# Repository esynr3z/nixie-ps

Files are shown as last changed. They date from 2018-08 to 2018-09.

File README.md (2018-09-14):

# Nixie power supply

## Features

High voltage flyback converter for nixie tubes

* Input voltage: 5V - 12V
* Output voltage: 150V - 200V
* Output power: 180V 20mA @ 5V in, 180V 40mA @ 12V in

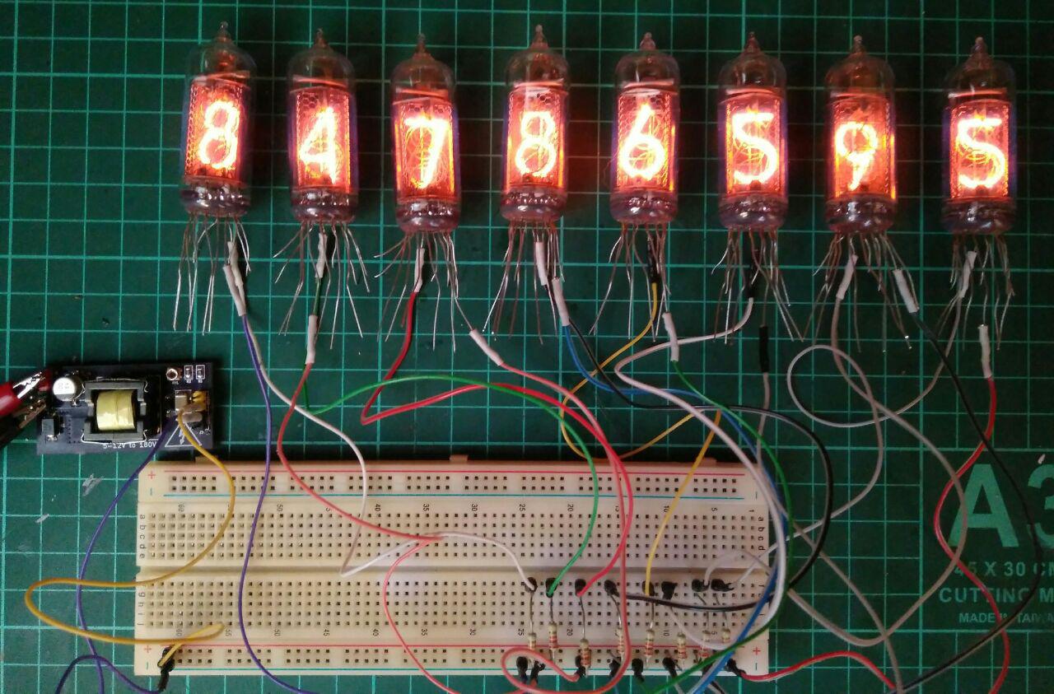
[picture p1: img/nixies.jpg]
nixies


## Board

Schematic and pcb layout created in KiCad 6 Nightly Build (compatible with KiCad 5). Converter also have been simulated with LTspice XVII.

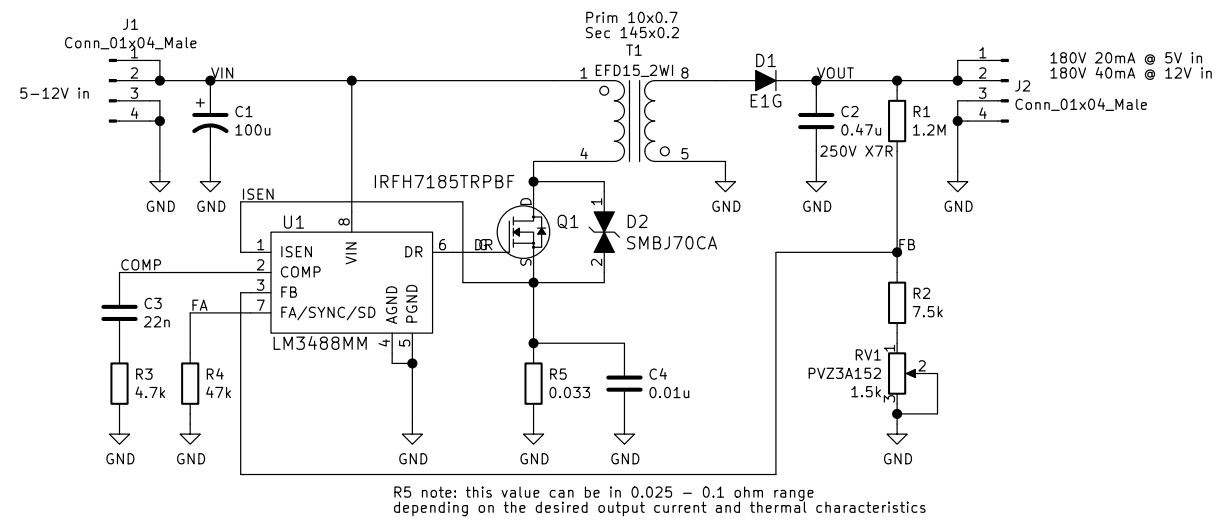
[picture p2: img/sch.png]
schematic

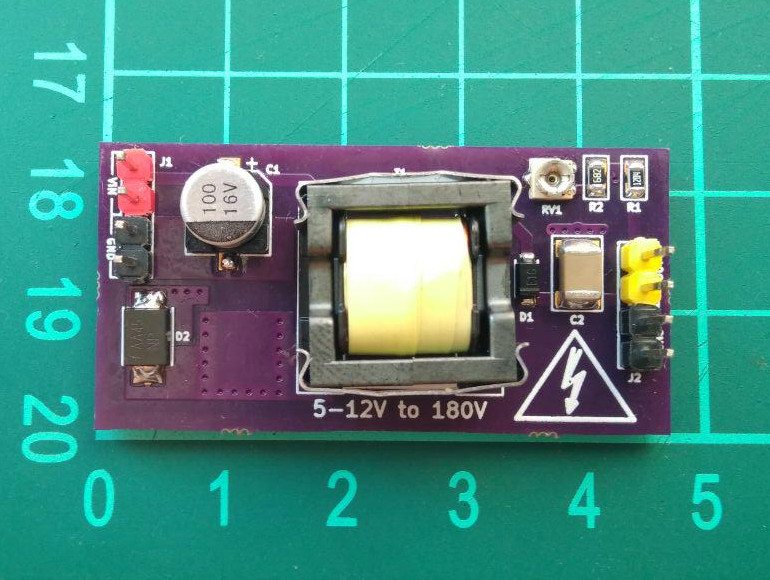
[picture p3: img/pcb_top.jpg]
pcb top

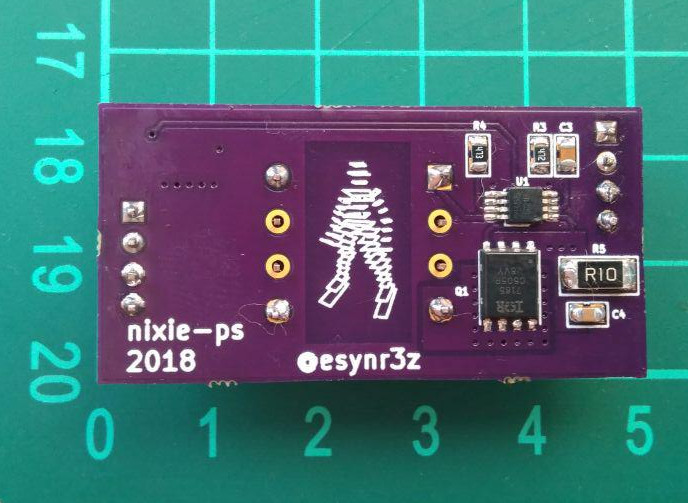
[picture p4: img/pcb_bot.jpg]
pcb bottom


[Order board v1.0 from OSH Park](https://oshpark.com/shared_projects/xFiD4IsX)

## Testing

### 5V input

Drain and gate oscillograms:
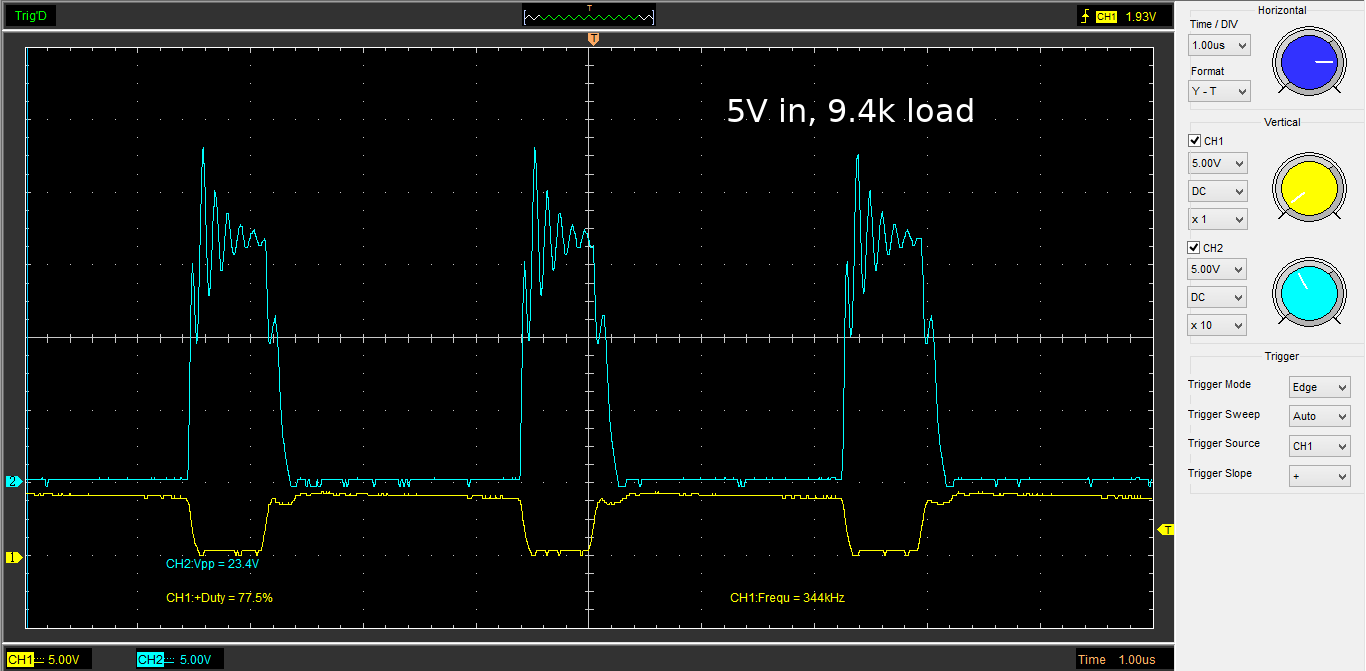
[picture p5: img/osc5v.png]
osc 5v


Measured characteristics:

| Vin, V | Iin, mA | Pin, W |  Rload, kOhm | Vout, V | Iout, mA | Pout, W | Eff, % |
|---:|---:|---:|---:|---:|---:|---:|---:|
| 5,34 | 82  | 0,44 | NC | 180,7 | - | - | - |
| 5,21 | 278  | 1,45 | 37,6 | 180,4 | 4,6 | 0,83 |  57,29 |
| 5,16 | 374  | 1,93 | 28,2 | 180,2 | 6,3 | 1,14 |  58,83 |
| 5,07 | 549  | 2,78 | 18,8 | 180,0 | 9,5 | 1,71 |  61,43 |
| 4,92 | 730  | 3,59 | 14,1 | 179,9 | 12,7 | 2,28 |  63,61 |
| 4,61 | 1170  | 5,39 | 9,4 | 179,5 | 19,2 | 3,45 |  63,90 |

### 12V input

Drain and gate oscillograms:
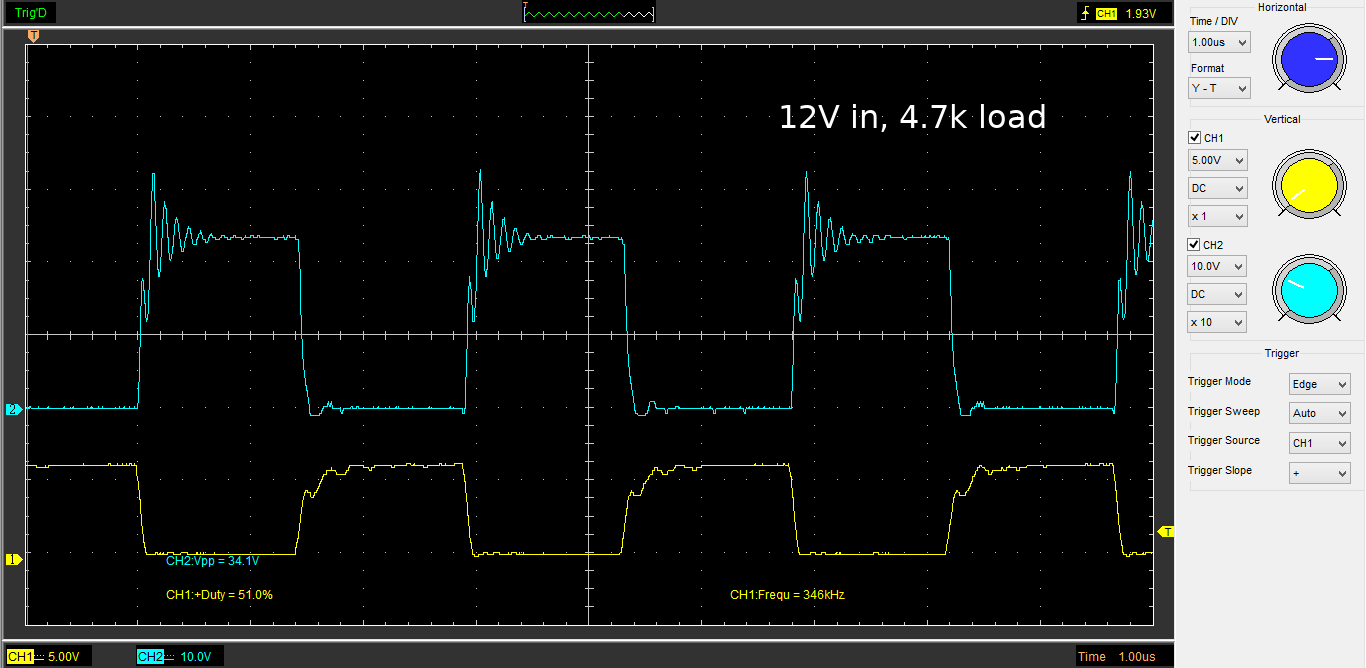
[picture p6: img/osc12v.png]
osc 12v


Measured characteristics:

| Vin, V | Iin, mA | Pin, W |  Rload, kOhm | Vout, V | Iout, mA | Pout, W | Eff, % |
|---:|---:|---:|---:|---:|---:|---:|---:|
|  12,52 | 17 | 0,21 | NC | 180,4 | - | - | - |
|  12,39 | 195 | 2,42 | 37,6 | 177,9 | 4,4 | 0,78 |  32,40 |
|  12,38 | 217 | 2,69 | 28,2 | 177,8 | 6,0 | 1,07 |  39,71 |
|  12,36 | 249 | 3,08 | 18,8 | 177,6 | 9,2 | 1,63 |  53,09 |
|  12,32 | 273 | 3,36 | 14,1 | 177,6 | 12,3 | 2,18 |  64,95 |
|  12,28 | 326 | 4,00 | 9,4 | 177,9 | 18,9 | 3,36 |  83,99 |
|  12,00 | 789 | 9,47 | 4,7 | 176,7 | 38,1 | 6,73 |  71,11 |

## Notes

* Output current limit can configured with R5 resistor. Less value - more current, but also more heating. With values <0.025 ohm converter may become unstable.
* D1 diode should be replaced with bigger one for operating with maximum current at 12V. Current SOD-123FL diode can be easily thermal destroyed in this mode.

## To do ...

* Improve mosfet layout for better heat dissipation
* Replace one shunt resistor (this values are rare) with 2-3 more generic nominals connected in parallel
* Add test points for drain and gate nets for debugging purpose
* More current, less temperature, more effeciency and etc.

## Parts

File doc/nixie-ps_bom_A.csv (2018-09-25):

Component | Description | Part | References | Value | Footprint | Quantity Per PCB | Datasheet | Rating | Notes
1 |  | Device_C | C4 | 0.01u | 0805 | 1 | ~
2 |  | Device_C | C2 | 0.47u | 1812 | 1 | ~ | 250V X7R
3 |  | Device_CP1 | C1 | 100u | CP_Elec_6.3x5.4 | 1 | ~
4 |  | Device_C | C3 | 22n | 0805 | 1 | ~
5 |  | esynr3z_DiodeRectifier_E1G | D1 | E1G | SOD-123FL | 1 | http://www.lrc.cn/data/pdf/SODE1J-SH.pdf
6 |  | esynr3z_DiodeTVS_SMBJ70CA | D2 | SMBJ70CA | SMB | 1 | http://www.littelfuse.com/~/media/electronics/datasheets/tvs_diodes/littelfuse_tvs_diode_smbj_datasheet.pdf.pdf
7 |  | Connector_Conn_01x04_Male | J1 J2 | Conn_01x04_Male | PinHeader_1x04_P2.54mm_Vertical | 2 | ~
8 |  | esynr3z_TransistorFET_IRFH7185TRPBF | Q1 | IRFH7185TRPBF | PQFN_5X6MM | 1 | https://www.infineon.com/dgdl/irfh7185pbf.pdf?fileId=5546d462533600a40153561ee0b11ee1
9 |  | Device_R | R5 | 0.033 | 2010 | 1 | ~
10 |  | Device_R | R1 | 1.2M | 0805 | 1 | ~
11 |  | Device_R | R3 | 4.7k | 0805 | 1 | ~
12 |  | Device_R | R4 | 47k | 0805 | 1 | ~
13 |  | Device_R | R2 | 7.5k | 0805 | 1 | ~
14 |  | esynr3z_Potentiometer_PVZ3A | RV1 | PVZ3A152 | Murata_PVZ3A | 1 | ~ | 1.5k
15 |  | esynr3z_Transformer_EFD15_2WI | T1 | EFD15_2WI | EFD15_B66414W1008D001 | 1 | https://en.tdk.eu/inf/80/db/fer/efd_15_8_5.pdf |  | Windings: primary 10 turns x 0.7 mm, secondary 145 turns x 0.2 mm; Core: B66413U0100K187; Coil former: B66414W1008D001; Yokes: B66414B2000;
16 |  | esynr3z_RegulatorSwitching_LM3488MM | U1 | LM3488MM | VSSOP-8_3.0x3.0mm_P0.65mm | 1 | http://www.ti.com/lit/ds/symlink/lm3488q-q1.pdf
Component Groups: | 16
Component Count: | 17
Fitted Components: | 17
Number of PCBs: | 1
Total components: | 17
Schematic Version: | A
Schematic Date:
BoM Date: | Tue 25 Sep 2018 21:00:42 MSK
Schematic Source: | /home/esynr3z/MyRepos/nixie-ps/nixie-ps.sch
KiCad Version: | Eeschema 6.0.0-rc1-unknown-r13783-618182dc

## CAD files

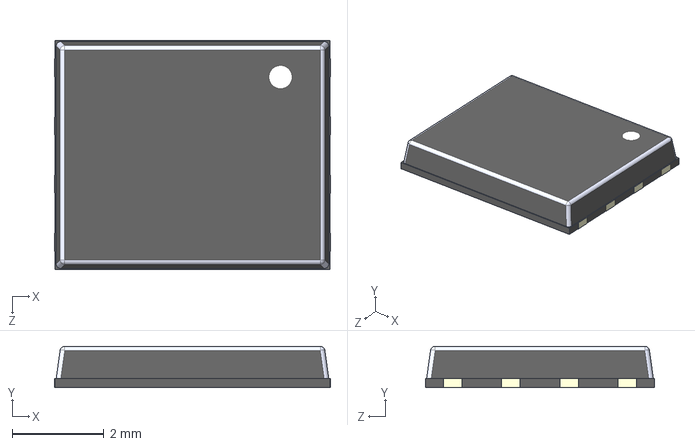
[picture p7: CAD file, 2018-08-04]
3d_models/PQFN_5X6MM.step
6.02 x 0.901 x 5.00 mm

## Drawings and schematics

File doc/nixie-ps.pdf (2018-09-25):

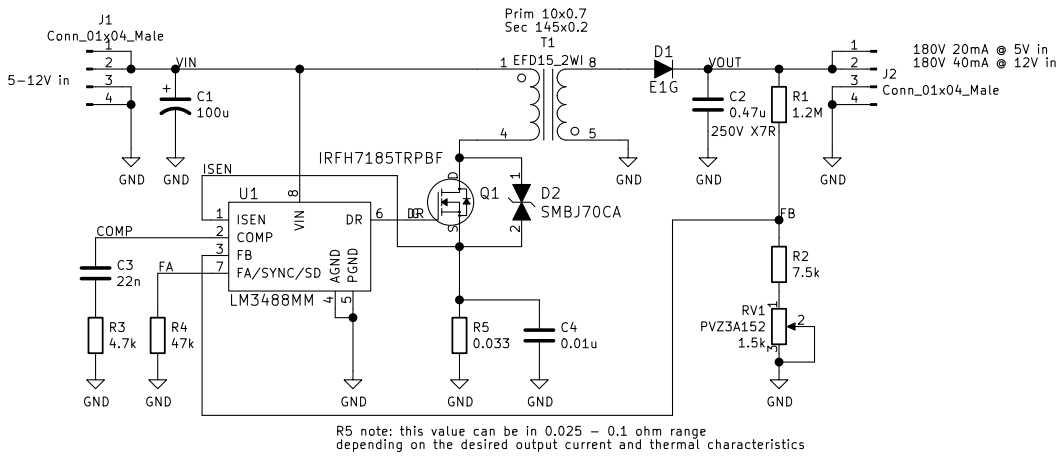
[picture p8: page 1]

depending on the desired output current and thermal characteristics Prim 10x0.7 Sec 145x0.2

5 DR 6 FA/SYNC/SD 7 VIN U1 8 LM3488MM

R5 note: this value can be in 0.025 - 0.1 ohm range

File: nixie-ps.sch Sheet: /
Id: 1/1 Title: High voltage power supply unit for Nixie tubes

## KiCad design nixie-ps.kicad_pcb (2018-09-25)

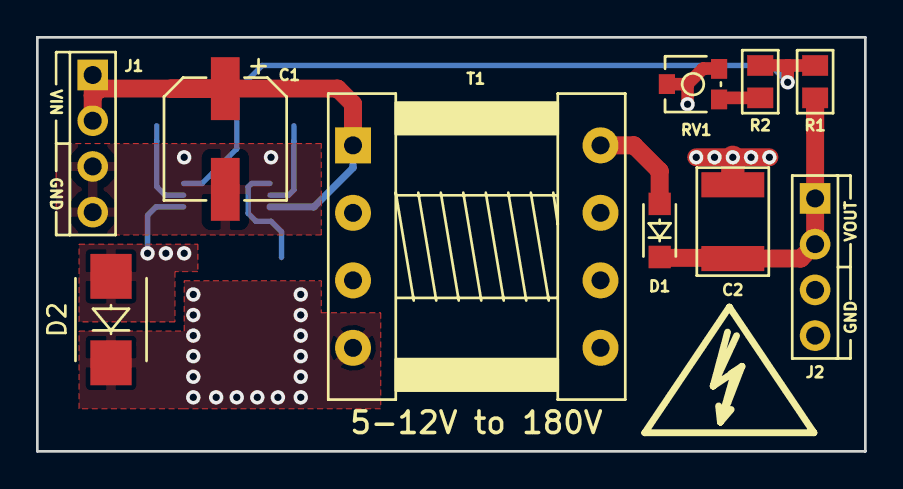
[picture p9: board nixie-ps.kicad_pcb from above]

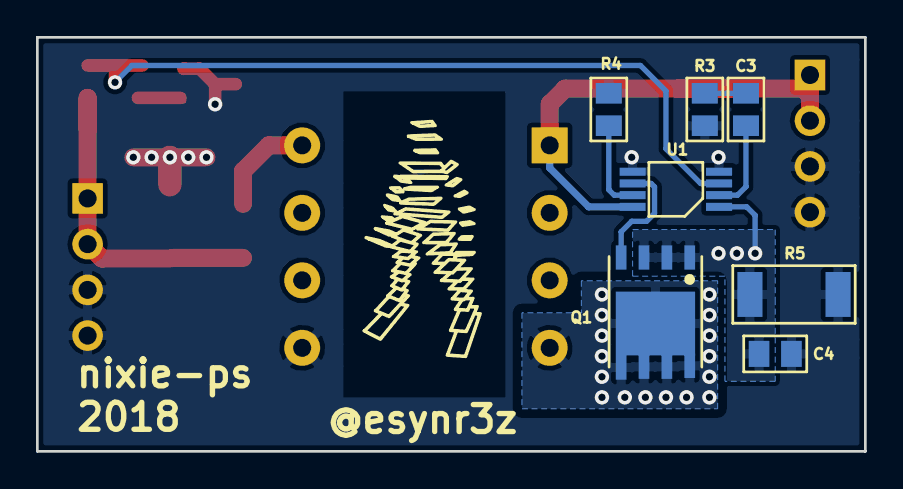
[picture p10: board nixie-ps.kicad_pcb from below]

Board: 2 copper layers, 46.0 x 23.0 mm, 17 parts (7 on the bottom side), 12 nets.

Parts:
C1: 100u; CP_Elec_6.3x5.4
C2: 0.47u; 1812
C3: 22n; 0805
C4: 0.01u; 0805
D1: E1G; SOD-123FL
D2: SMBJ70CA; SMB
J1, J2: Conn_01x04_Male; PinHeader_1x04_P2.54mm_Vertical
Q1: IRFH7185TRPBF; PQFN_5X6MM
R1: 1.2M; 0805
R2: 7.5k; 0805
R3: 4.7k; 0805
R4: 47k; 0805
R5: 0.033; 2010
RV1: PVZ3A152; Murata_PVZ3A
T1: EFD15_2WI; EFD15_B66414W1008D001
U1: LM3488MM; VSSOP-8_3.0x3.0mm_P0.65mm

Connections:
/COMP: C3.1, U1.2
/DR: Q1.4, U1.6
/FA: R4.1, U1.7
/FB: R1.2, R2.1, U1.3
/ISEN: C4.1, D2.2, Q1.1, Q1.2, Q1.3, R5.1, U1.1
/VIN: C1.1, J1.1, J1.2, T1.1, U1.8
/VOUT: C2.1, D1.1, J2.1, J2.2, R1.1
GND: C1.2, C2.2, C4.2, J1.3, J1.4, J2.3, J2.4, R3.2, R4.2, R5.2, RV1.2, RV1.3, T1.5, U1.4, U1.5
unnamed: C3.2, R3.1
unnamed: D1.2, T1.8
unnamed: D2.1, Q1.5, Q1.6, Q1.7, Q1.8, T1.4
unnamed: R2.2, RV1.1

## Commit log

2018-07-02 Replace IRFH5106PBF to RFH7185TRPBF Replace resistor Isense footprint to bigger one Also update ltspice scheme with last changes
    [nixie-ps.kicad_pcb, nixie-ps.sch]
2018-07-03 Reroute board left side
    [nixie-ps.kicad_pcb]
2018-07-03 Board minor fixes and gerber update
    [nixie-ps-B.Cu.gbl, nixie-ps-B.Mask.gbs, nixie-ps-B.SilkS.gbo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]
2018-07-03 Fix C3 R3 references position on silk layer
    [nixie-ps-B.Cu.gbl, nixie-ps-B.Mask.gbs, nixie-ps-B.SilkS.gbo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]
2018-07-03 ????????? ????? board_order ??? ?????? ????????? 488ec9a40053
2018-08-04 Update to KiCAD 6.0.0-rc1
    [nixie-ps.kicad_pcb]
2018-08-04 Fix elec cap 3d model
    [nixie-ps.kicad_pcb]
2018-08-04 Make project fully portable
    [PQFN_5X6MM.step, nixie-ps.kicad_pcb, nixie-ps.sch]
2018-08-13 Prepare sch and pcb for generating docs
    [nixie-ps.kicad_pcb, nixie-ps.sch]
2018-08-13 Add title to sch
    [nixie-ps.sch]
2018-08-23 Check ltspice model at 5v and 12v
2018-08-26 Update sch and pcb after latest simulation
    [nixie-ps.kicad_pcb, nixie-ps.sch]
2018-09-14 Massive update after debuging and testing
    [nixie-ps.kicad_pcb, nixie-ps.sch]
2018-09-21 Add BOM
    [nixie-ps.sch, nixie-ps_bom_v1.0.csv]
2018-09-25 Set revision A in all sheets
    [nixie-ps.kicad_pcb, nixie-ps.sch, nixie-ps_bom_A.csv]
